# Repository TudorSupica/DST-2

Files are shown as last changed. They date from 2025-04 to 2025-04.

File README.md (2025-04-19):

# The [DST-2](https://github.com/TudorSupica/DST-2/)
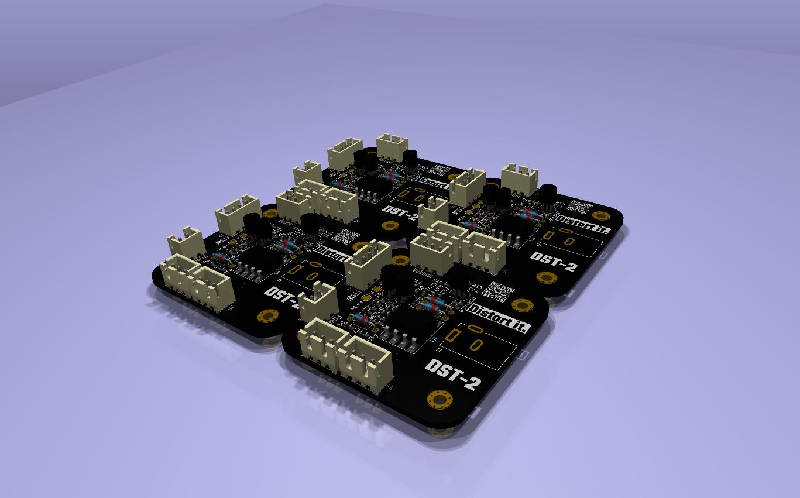
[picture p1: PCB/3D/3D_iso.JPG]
isometric


   The DST-2 is the second version of the DST distortion pedal series. It's main goal was to make the pedal a whole lot modular and easier to debug, since I want all the future pedals to be compatible with one another. 
  
  The modularity comes from the use of JST connectors and the use of modules like the [TMC-1](https://github.com/TudorSupica/TMC-1) and the [TMF](https://github.com/TudorSupica/TMF). These modules aim to standardise the pedal-making process and to make all the future pedals compatible.

  The debugging aspect of the board comes from the use of test pads labled accordingly, so that when eventually a problem arises, they can be debugged and fixed. The test pads I added mainly target features like power supply and signal line. I also connected the four screw holes found in the corners of the board to GND, so that when debigging I won't have to actively look for a GND test point.

  Another feature that I introduced with this board is the use of SMD components rather than THT ones (except for like, a couple diodes and the transistors). This change aimed to minimize the board size, to ensure it is going to fit alongside the other modules in the metal enclosure.

  # [The Schematic](https://github.com/TudorSupica/DST-2/blob/main/Schematic/)
   The schematic is made up of a few blocks: a buffer stage, initial amplifying stage, a variable gain stage, clipping stage, filtering stage and a final buffer stage. 

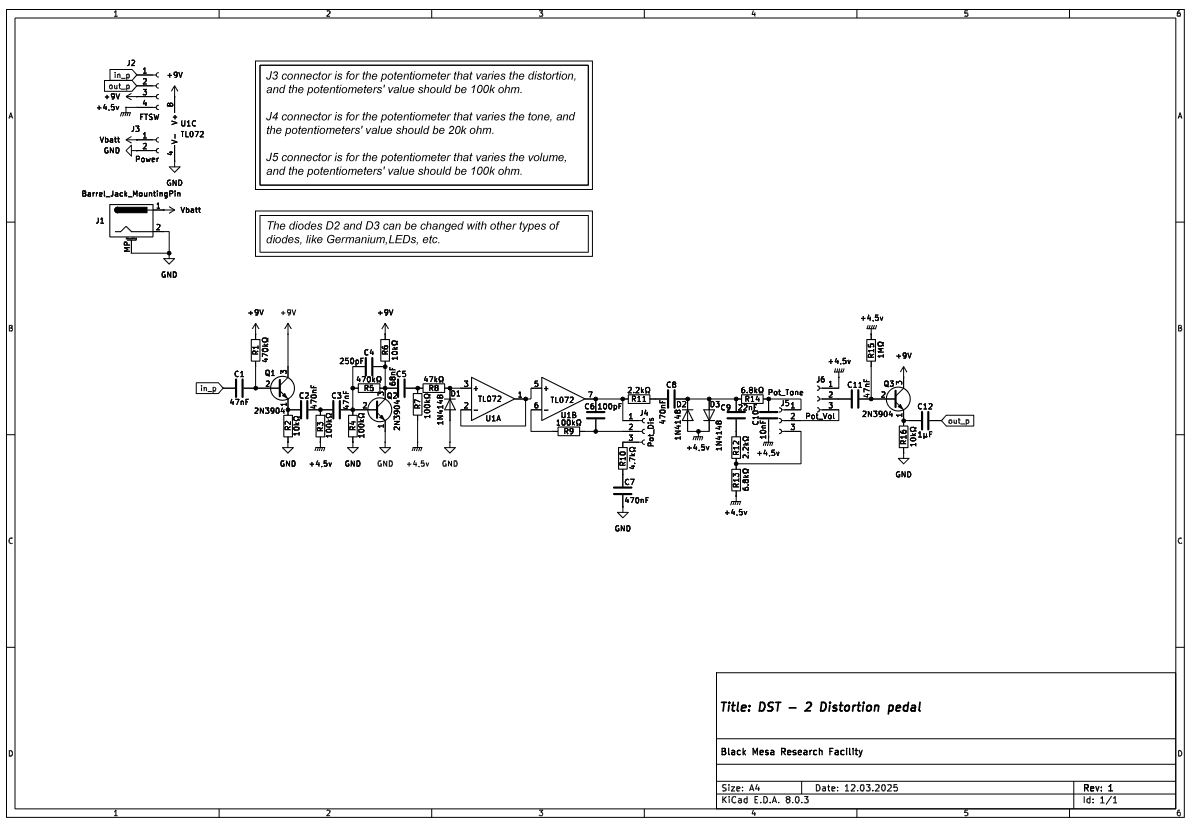
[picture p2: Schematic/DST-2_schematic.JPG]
Schematic


   ### The buffer stage 
   The buffer stage is a voltage follower made up of the transistor *Q1* and *R1*, *R2* and *C1*, *C2*.
   
   This stage has a voltage gain of (*ideally*) 1, so that the voltage at the collector of *Q1* is exactly the signal but 180º out of phase (*basically the signal but inverted, lmao maths*). But the real advantage of the buffer stage comes from the high-impedance input and low-impedance output of the stage. 
  
   The resistor *R1* biases the transistor whilst the resistor *R2* provides thermal stability (*you **could** add another capacitor in parallel with R2, so that it shorts at higher frequencies providing better stability thus a better frequency responce*). The capacitors *C1* and *C2* are decoupling capacitors, they eliminate the DC characteristic of the signal so that I can bias it however I need to (*again, lmao maths*).

   ### The initial amplifying stage
   The initial amplifying stage is made up of the transistor *Q2*, the resistors *R3* thru *R6* and the capacitors *C3* thru *C5*.

   The resistor *R3* and capacitor *C3* make up a high-pass filter with a cutoff frequency of about 33 Hz. The capacitor *C3* is also used to decouple the signal, and the resistor *R4* is used to bias the base signal of the transistor *Q2*.

   The resistor *R5* and the capacitor *C4* make up the feedback loop of the stage, whilst the resistor *R6* gives the amplifying ratio of the stage (*its ratio is roughly R6/internal resistance of the BE junction*).

   And finally the capacitor *C5* is used to decouple the signal before it reaches the next stage.

   ### The variable gain stage
   The variable gain stage is made up of a few components, mainly a double op-amp SOIC-8 IC (*even tho the TL072 or the LM358 work fine, I'd strongly recommend some better op-amps such as the OPA2134*) with some support components such as resistors and capacitors.
  
   # [The PCB](https://github.com/TudorSupica/DST-2/blob/main/PCB/)
  Yappa yappa PCB yappa yappa type shi

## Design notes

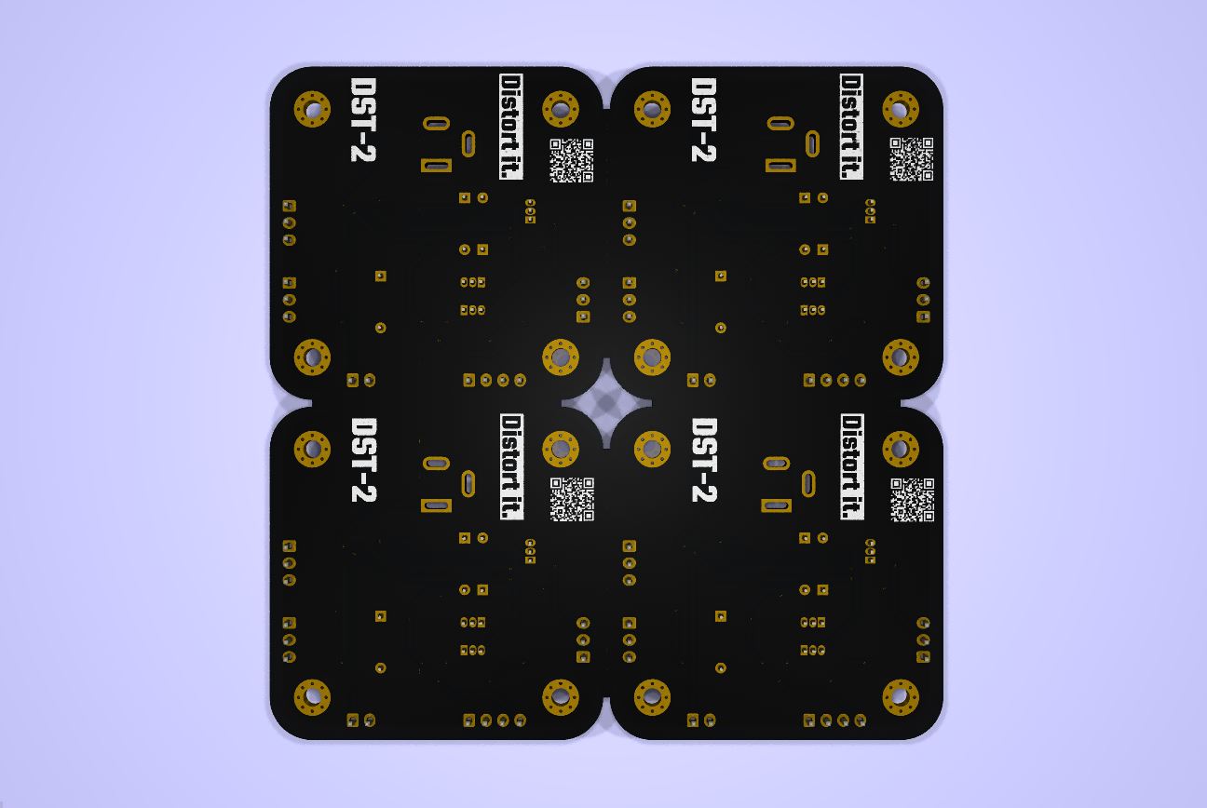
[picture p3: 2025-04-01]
PCB/3D/3D_back.JPG

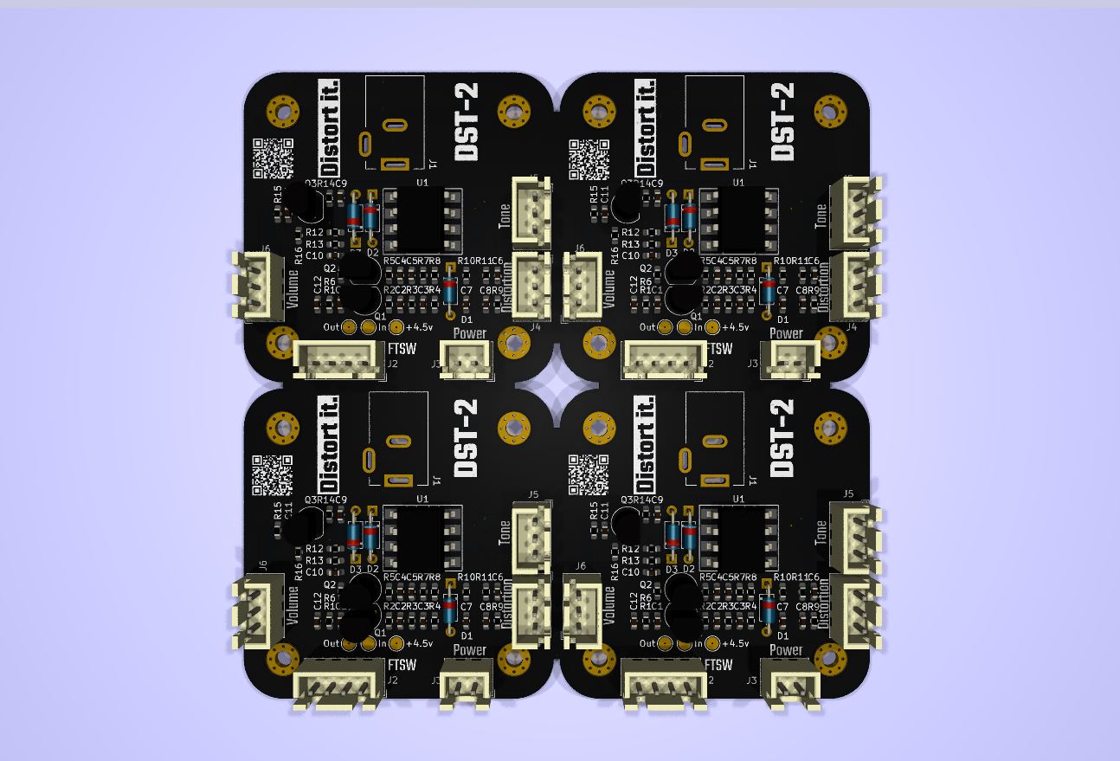
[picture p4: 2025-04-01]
PCB/3D/3D_front.JPG

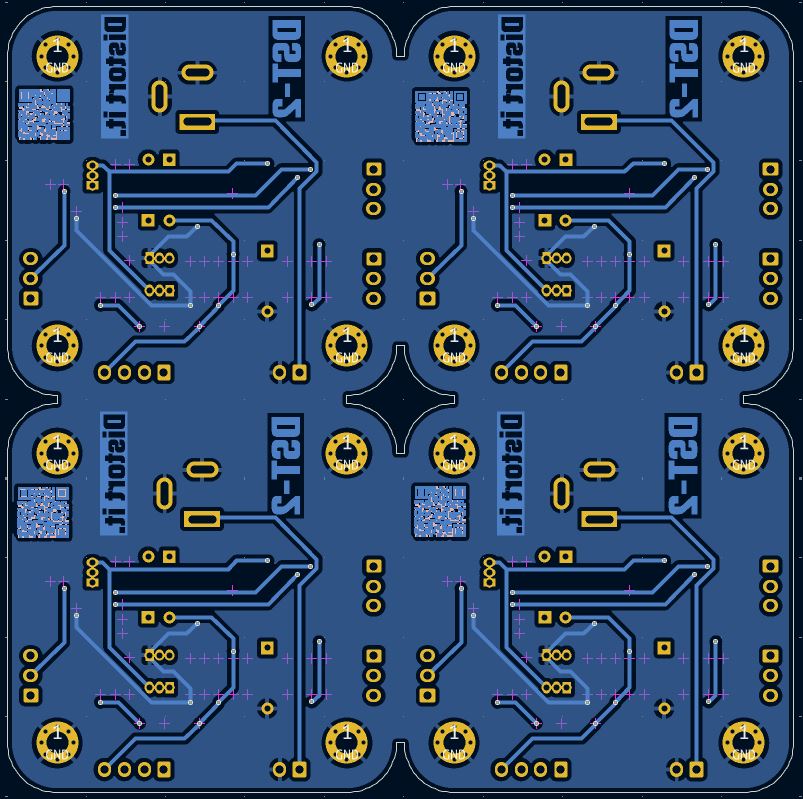
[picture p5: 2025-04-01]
PCB/2D/2D_back.JPG

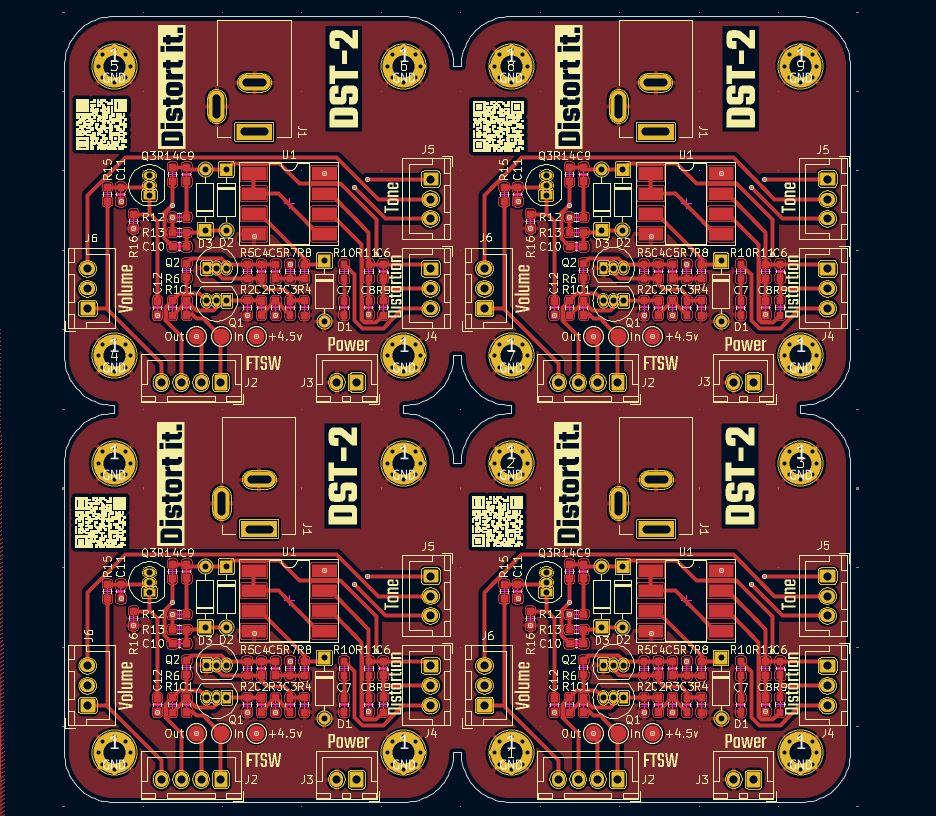
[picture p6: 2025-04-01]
PCB/2D/2D_front.JPG

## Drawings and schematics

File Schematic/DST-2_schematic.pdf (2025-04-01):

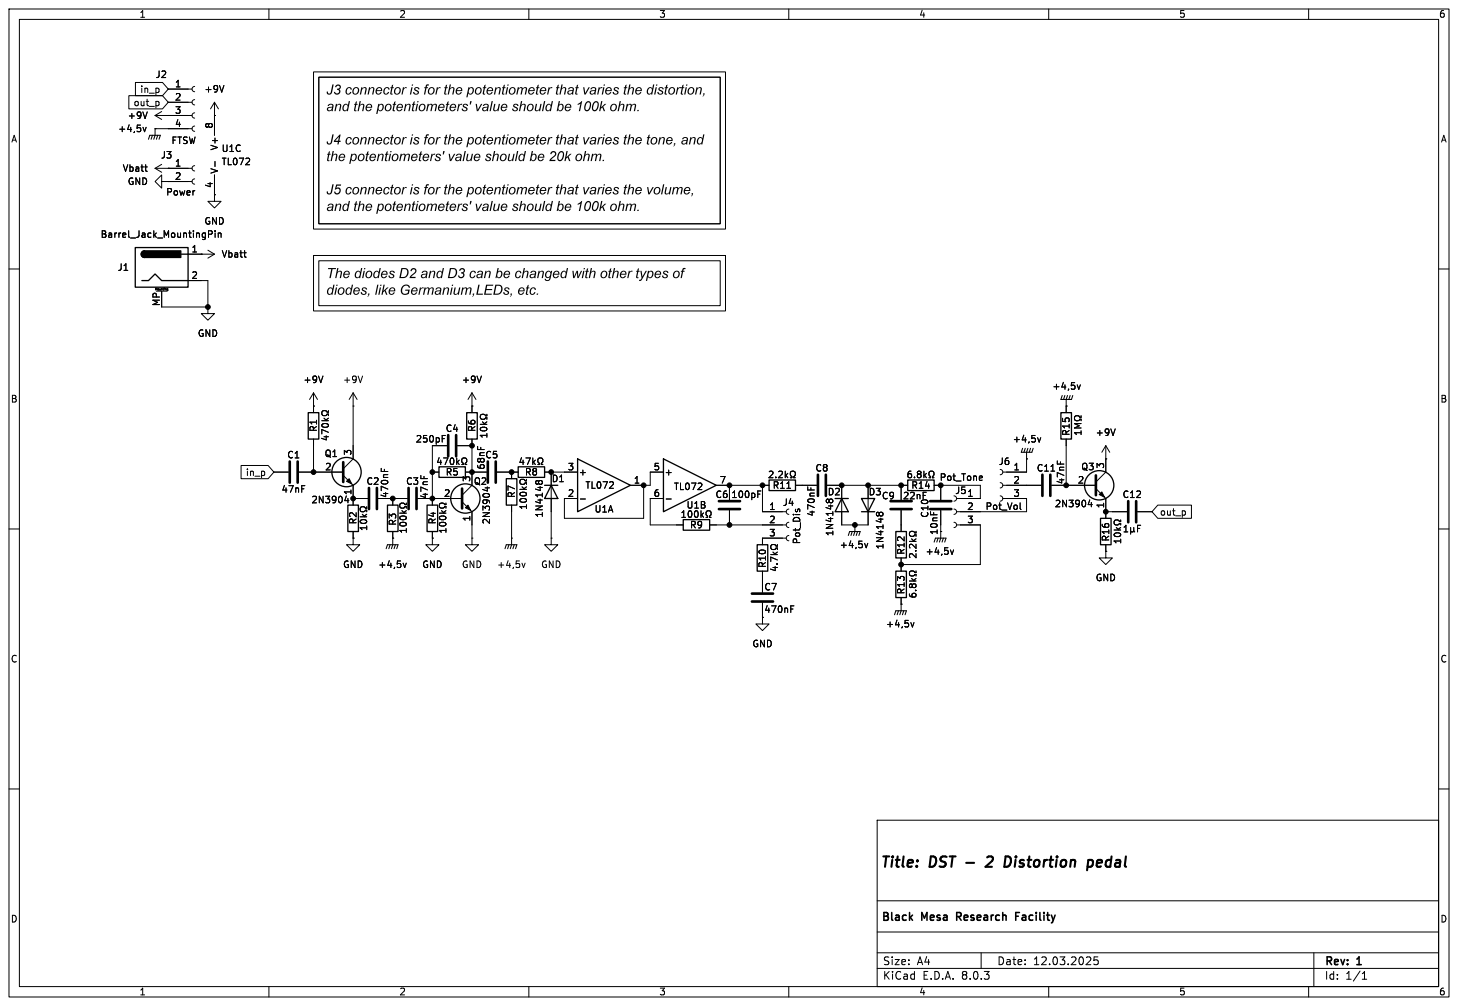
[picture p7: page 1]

J3 connector is for the potentiometer that varies the distortion,
and the potentiometers' value should be 100k ohm.

J4 connector is for the potentiometer that varies the tone, and
the potentiometers' value should be 20k ohm.

J5 connector is for the potentiometer that varies the volume,

The diodes D2 and D3 can be changed with other types of

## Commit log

2025-02-25 Uploaded PCB design
    [DST-2.kicad_pcb, DST-2.kicad_sch]
2025-04-01 Added the pcb and the gerbers
    [DST-2-B_Cu.gbr, DST-2-B_Mask.gbr, DST-2-B_Paste.gbr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]
